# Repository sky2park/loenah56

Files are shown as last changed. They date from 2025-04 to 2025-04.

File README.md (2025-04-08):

# loenah56
Loenah56, A split-keyboard with 56 keys.

# How to flash firmware
Use qmk toolbox. Copy loenah folder to qmk toolbox keyboard folder.

Connect one side with bootloader mode. Execute qmk toolbox and execute below line.

qmk flash -kb loenah -km default -bl uf2-split-left (for left)

qmk flash -kb loenah -km default -bl uf2-split-right (for right)

Connect other side and do as same.

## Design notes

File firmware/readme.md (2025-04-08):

# loenah

loenah

*A short description of the keyboard/project*

* Keyboard Maintainer: [Park](https://github.com/sky2park)
* Hardware Supported: *The PCBs, controllers supported*
* Hardware Availability: *Links to where you can find this hardware*

Make example for this keyboard (after setting up your build environment):

    make loenah:default

Flashing example for this keyboard:

    make loenah:default:flash

See the [build environment setup](https://docs.qmk.fm/#/getting_started_build_tools) and the [make instructions](https://docs.qmk.fm/#/getting_started_make_guide) for more information. Brand new to QMK? Start with our [Complete Newbs Guide](https://docs.qmk.fm/#/newbs).

## Bootloader

Enter the bootloader in 3 ways:

* **Bootmagic reset**: Hold down the key at (0,0) in the matrix (usually the top left key or Escape) and plug in the keyboard
* **Physical reset button**: Briefly press the button on the back of the PCB - some may have pads you must short instead
* **Keycode in layout**: Press the key mapped to `QK_BOOT` if it is available

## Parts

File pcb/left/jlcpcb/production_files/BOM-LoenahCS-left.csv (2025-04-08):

Comment | Designator | Footprint | LCSC | Quantity
Resistor | R1,R2 | Resistor_0402 | C25905 | 2
MX_SW_HS | MX1,MX10,MX11,MX12,MX13,MX14,MX15,MX16,MX17,MX18,MX19,MX2,MX20,MX21,MX22,MX23,MX24,MX25,MX26,MX27,MX28,MX3,MX4,MX5,MX6,MX7,MX8,MX9 | SW_MX_HS_CPG151101S11_1u | C41430893 | 28
D_Small | D1,D10,D11,D12,D13,D14,D15,D16,D17,D18,D19,D2,D20,D21,D22,D23,D24,D25,D26,D27,D28,D3,D4,D5,D6,D7,D8,D9 | D_SOD-123 | C83528 | 28

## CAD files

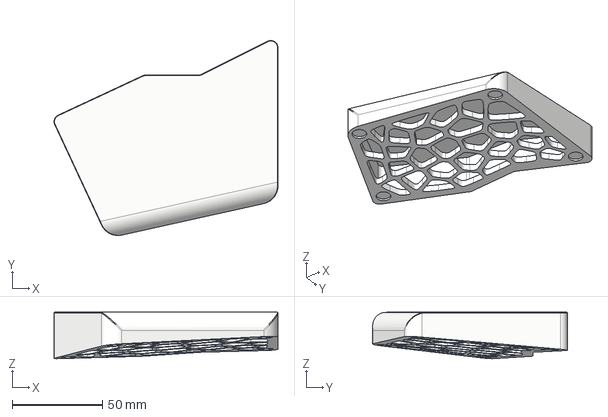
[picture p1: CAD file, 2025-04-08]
case/palmrest_right.step
124.4 x 108.3 x 25.8 mm

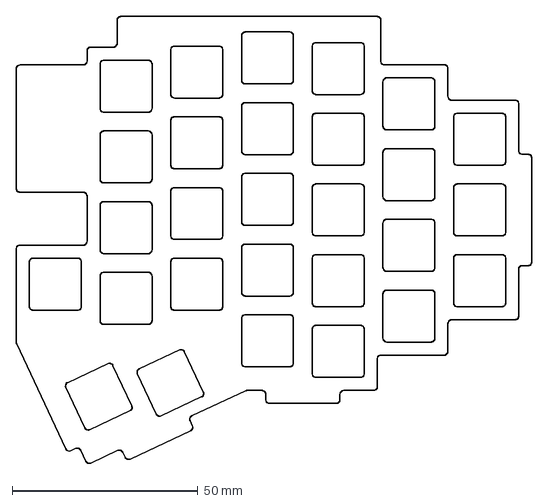
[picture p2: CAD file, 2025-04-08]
plate/plate_right.dxf
138.9 x 120.4 mm

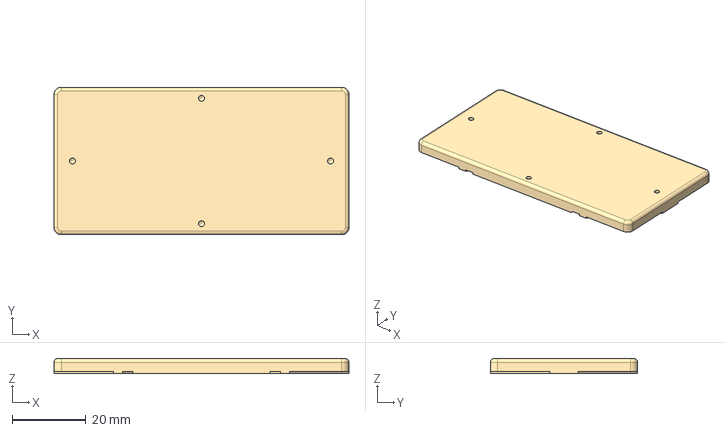
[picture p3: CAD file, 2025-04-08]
case/counterweight.step
80.0 x 40.0 x 4.00 mm

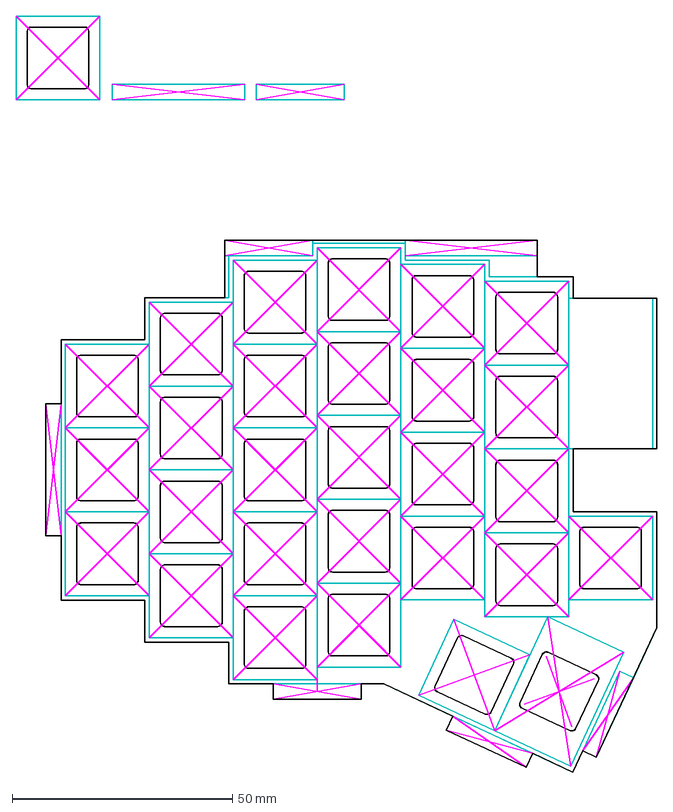
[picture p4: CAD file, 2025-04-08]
plate/design_criteria.dxf
145.6 x 171.7 mm

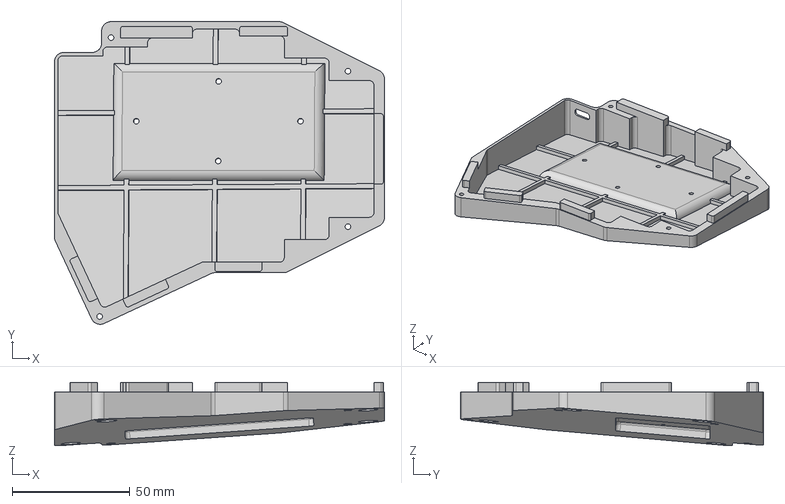
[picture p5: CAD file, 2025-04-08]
case/bottom_right.step
140.4 x 128.7 x 26.9 mm

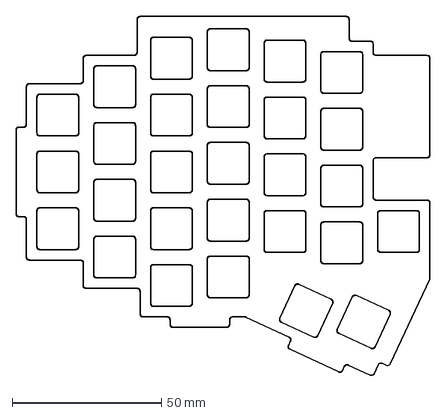
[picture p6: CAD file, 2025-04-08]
plate/plate_left.dxf
138.9 x 120.4 mm

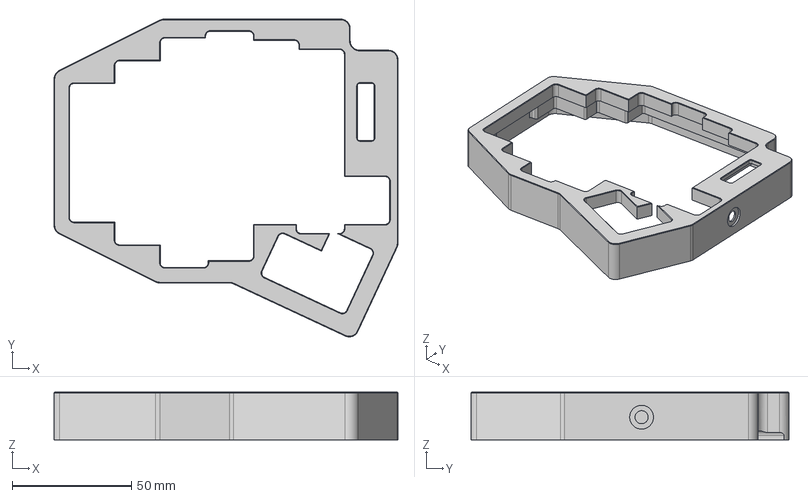
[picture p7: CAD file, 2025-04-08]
case/top_left.step
144.3 x 133.4 x 20.0 mm

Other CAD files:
case/palmrest_left.step
case/bottom_left.step
case/top_right.step

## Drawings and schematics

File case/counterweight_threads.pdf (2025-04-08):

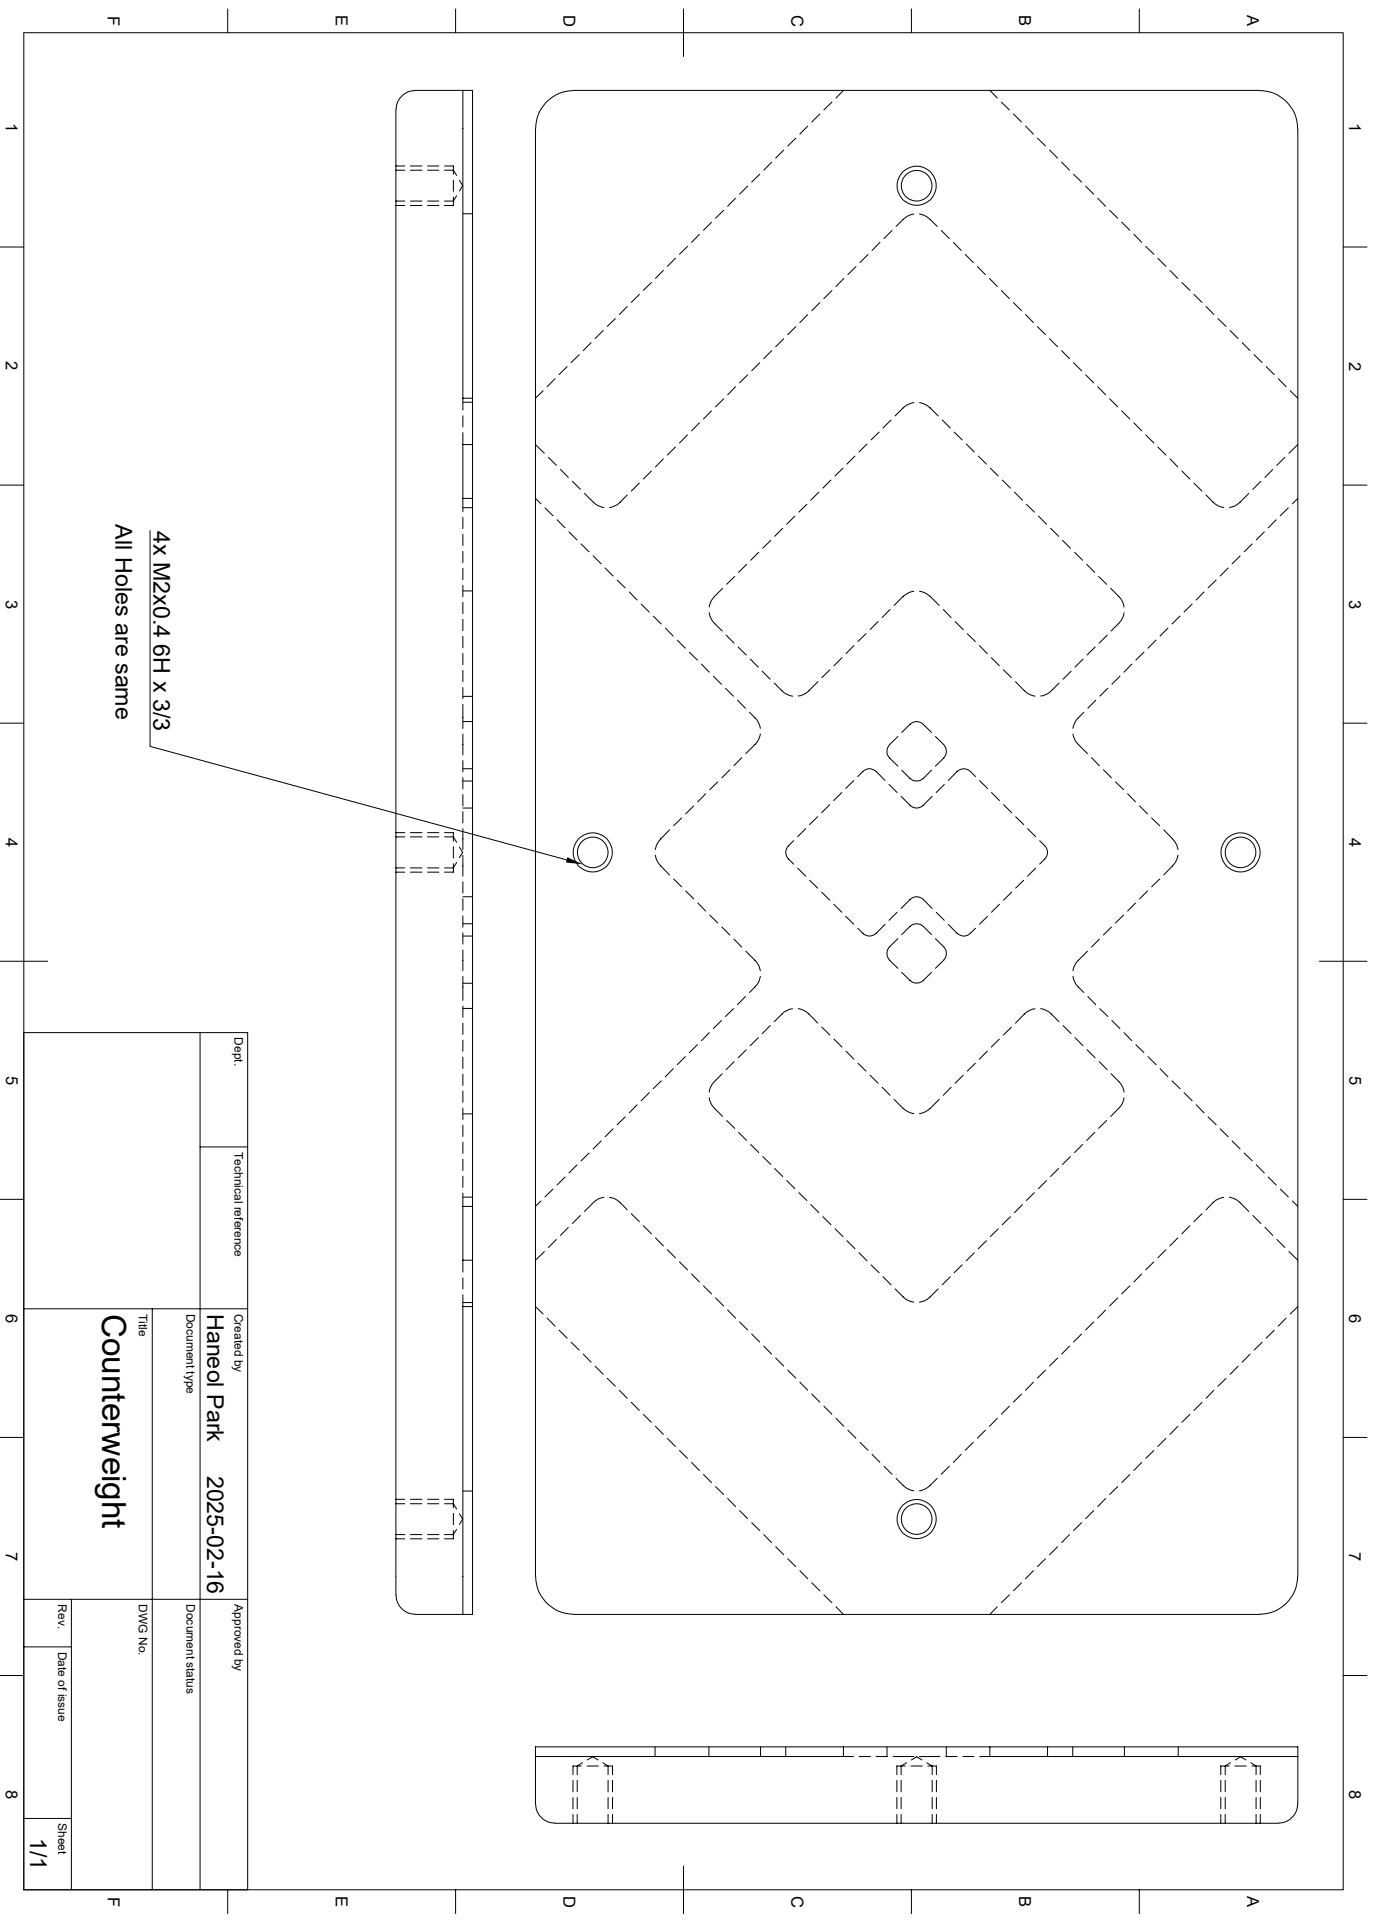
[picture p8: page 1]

1 A 2 3 4 5 6 7 8 1 2 3 4 5 6 7 8 FEDCB FEDCBA Dept. Technical reference Created by Approved by Title DWG No. Document type Document status Rev. Date of issue Sheet 2025-02-16 1/1 Counterweight Haneol Park All Holes are same 4x M2x0.4 6H x 3/3

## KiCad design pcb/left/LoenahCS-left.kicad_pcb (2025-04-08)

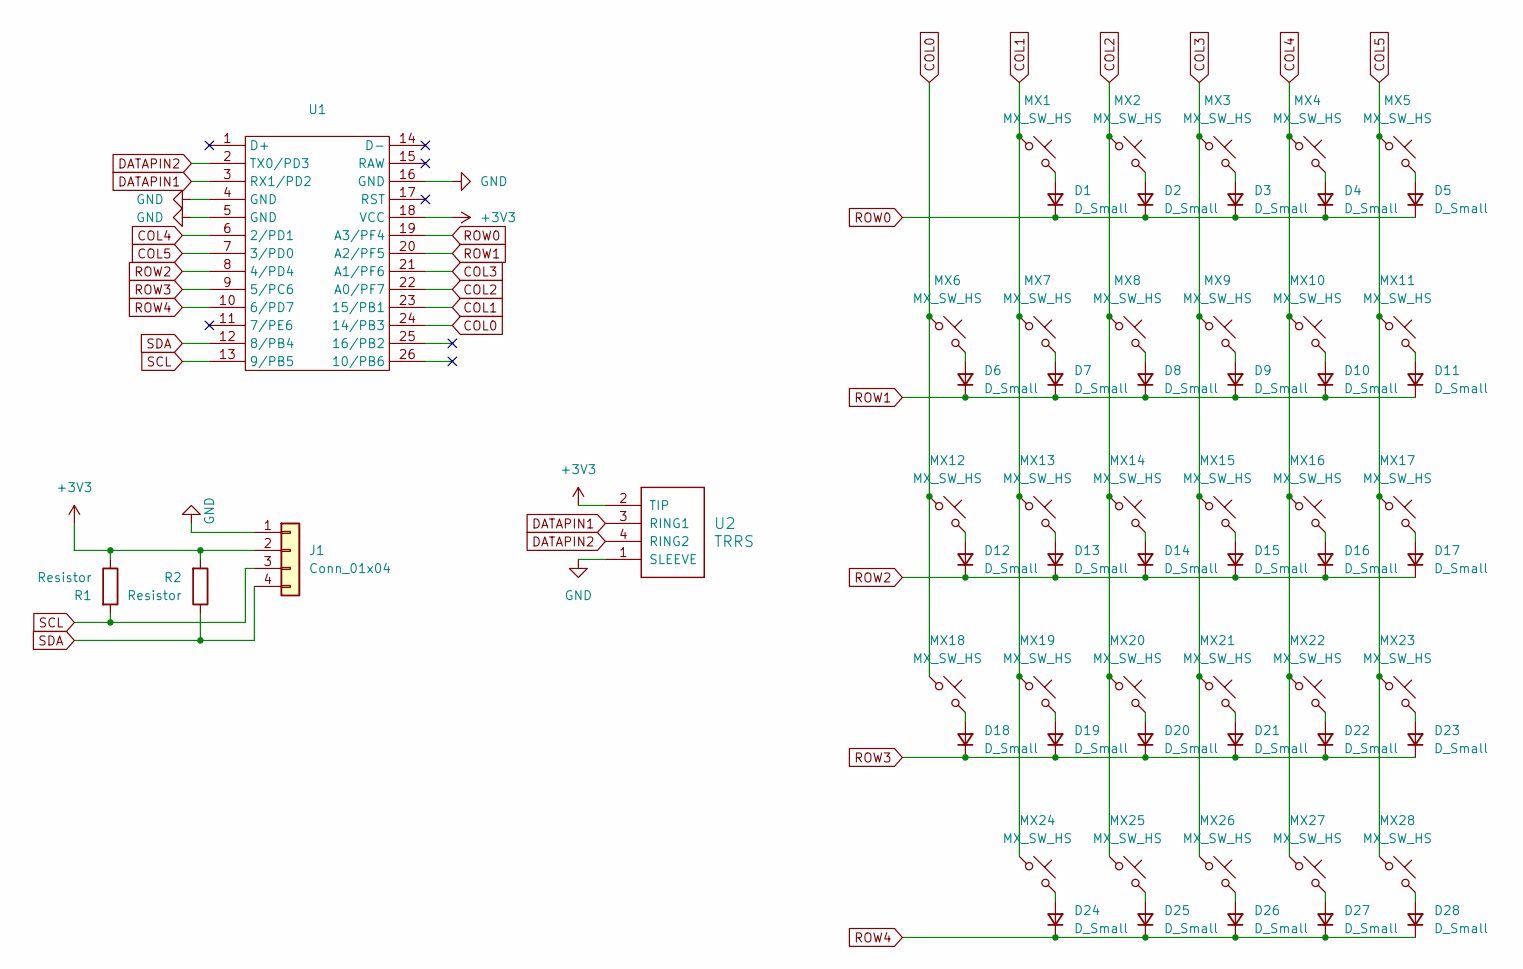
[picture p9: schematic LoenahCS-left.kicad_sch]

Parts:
D1, D2, D3, D4, D5, D6, D7, D8, D9, D10, D11, D12, D13, D14, D15, D16, D17, D18, D19, D20, D21, D22, D23, D24, D25, D26, D27, D28: D_Small; D_SOD-123
J1: Conn_01x04; PinHeader_1x04_P2.54mm_Vertical
MX1, MX2, MX3, MX4, MX5, MX6, MX7, MX8, MX9, MX10, MX11, MX12, MX13, MX14, MX15, MX16, MX17, MX18, MX19, MX20, MX21, MX22, MX23, MX24, MX25, MX26, MX28: MX_SW_HS; SW_MX_HS_CPG151101S11_1u
MX27: MX_SW_HS; SW_MX_HS_CPG151101S11_1.5u
R1, R2: Resistor; Resistor_0402
U1: Adafruit_KB2040
U2: TRRS; TRRS_PJ-320A

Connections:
+3V3: J1.2, R1.1, R2.2, U1.18 (VCC), U2.2 (TIP)
COL0: MX6.1, MX12.1, MX18.1, U1.24 (14/PB3)
COL1: MX1.1, MX7.1, MX13.1, MX19.1, MX24.1, U1.23 (15/PB1)
COL2: MX2.1, MX8.1, MX14.1, MX20.1, MX25.1, U1.22 (A0/PF7)
COL3: MX3.1, MX9.1, MX15.1, MX21.1, MX26.1, U1.21 (A1/PF6)
COL4: MX4.1, MX10.1, MX16.1, MX22.1, MX27.1, U1.6 (2/PD1)
COL5: MX5.1, MX11.1, MX17.1, MX23.1, MX28.1, U1.7 (3/PD0)
DATAPIN1: U1.3 (RX1/PD2), U2.3 (RING1)
DATAPIN2: U1.2 (TX0/PD3), U2.4 (RING2)
GND: J1.1, U1.4 (GND), U1.5 (GND), U1.16 (GND), U2.1 (SLEEVE)
unnamed: D1.2 (A), MX1.2
unnamed: D2.2 (A), MX2.2
unnamed: D3.2 (A), MX3.2
unnamed: D4.2 (A), MX4.2
unnamed: D5.2 (A), MX5.2
unnamed: D6.2 (A), MX6.2
unnamed: D7.2 (A), MX7.2
unnamed: D8.2 (A), MX8.2
unnamed: D9.2 (A), MX9.2
unnamed: D10.2 (A), MX10.2
unnamed: D11.2 (A), MX11.2
unnamed: D12.2 (A), MX12.2
unnamed: D13.2 (A), MX13.2
unnamed: D14.2 (A), MX14.2
unnamed: D15.2 (A), MX15.2
unnamed: D16.2 (A), MX16.2
unnamed: D17.2 (A), MX17.2
unnamed: D18.2 (A), MX18.2
unnamed: D19.2 (A), MX19.2
unnamed: D20.2 (A), MX20.2
unnamed: D21.2 (A), MX21.2
unnamed: D22.2 (A), MX22.2
unnamed: D23.2 (A), MX23.2
unnamed: D24.2 (A), MX24.2
unnamed: D25.2 (A), MX25.2
unnamed: D26.2 (A), MX26.2
unnamed: D27.2 (A), MX27.2
unnamed: D28.2 (A), MX28.2
ROW0: D1.1 (K), D2.1 (K), D3.1 (K), D4.1 (K), D5.1 (K), U1.19 (A3/PF4)
ROW1: D6.1 (K), D7.1 (K), D8.1 (K), D9.1 (K), D10.1 (K), D11.1 (K), U1.20 (A2/PF5)
ROW2: D12.1 (K), D13.1 (K), D14.1 (K), D15.1 (K), D16.1 (K), D17.1 (K), U1.8 (4/PD4)
ROW3: D18.1 (K), D19.1 (K), D20.1 (K), D21.1 (K), D22.1 (K), D23.1 (K), U1.9 (5/PC6)
ROW4: D24.1 (K), D25.1 (K), D26.1 (K), D27.1 (K), D28.1 (K), U1.10 (6/PD7)
SCL: J1.3, R1.2, U1.13 (9/PB5)
SDA: J1.4, R2.1, U1.12 (8/PB4)

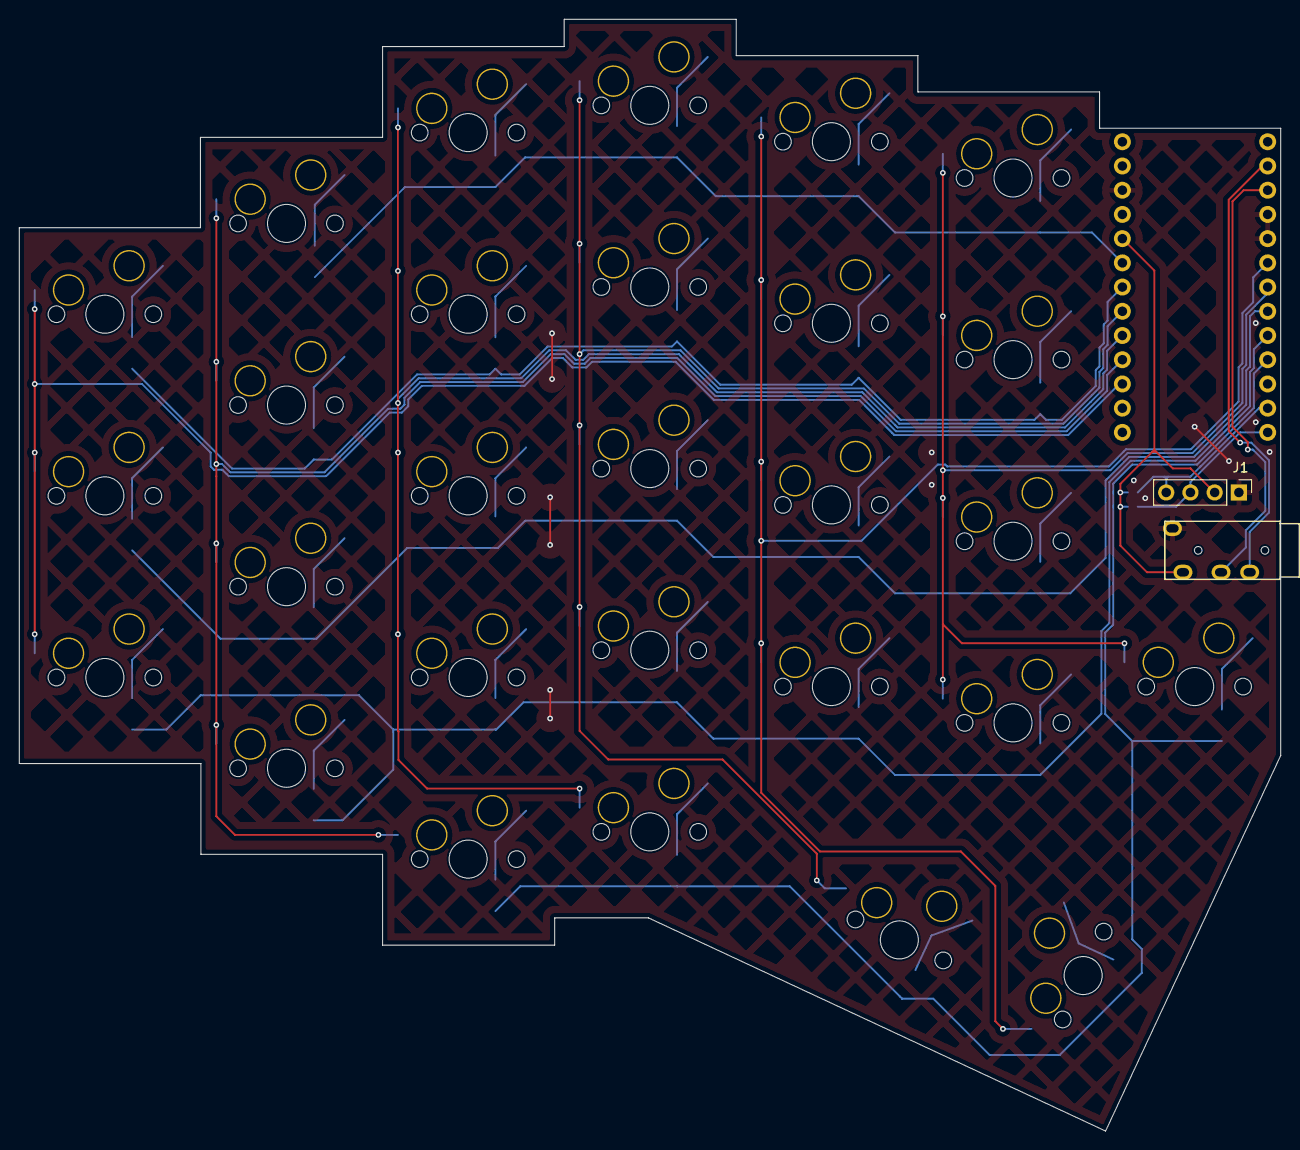
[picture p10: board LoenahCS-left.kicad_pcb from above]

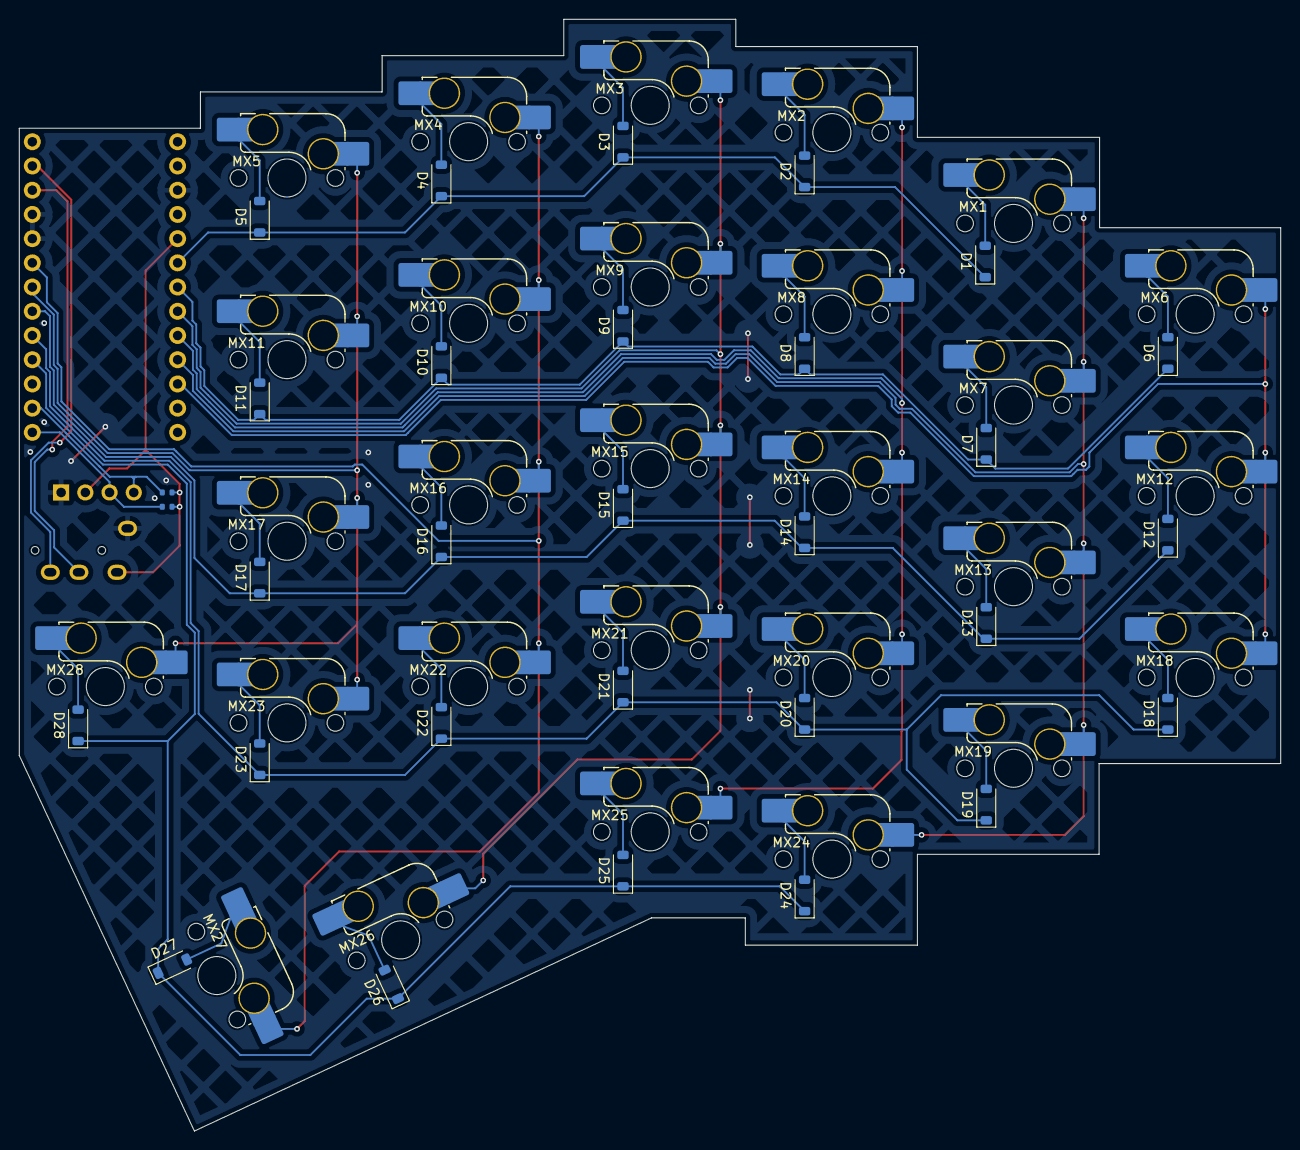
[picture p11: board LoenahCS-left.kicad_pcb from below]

Board: 2 copper layers, 132.3 x 116.6 mm, 61 parts (59 on the bottom side), 45 nets.

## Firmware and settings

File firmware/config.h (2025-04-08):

#pragma once

#define OLED_FONT_H "keyboards/loenah/lib/glcdfont.c"

#define EE_HANDS											// Flash handedness to each side (-bl uf2-split-left/right)
#define RP2040_BOOTLOADER_DOUBLE_TAP_RESET 					// Enable double-tapping reset button to enter bootloader mode
#define RP2040_BOOTLOADER_DOUBLE_TAP_RESET_TIMEOUT 500U		// How quickly reset button must be tapped to enter bootloader mode

#define BOOTMAGIC_ROW 0
#define BOOTMAGIC_COLUMN 1
#define BOOTMAGIC_ROW_RIGHT 5
#define BOOTMAGIC_COLUMN_RIGHT 4

#define SERIAL_USART_FULL_DUPLEX    						// USART full duplex
#define SERIAL_USART_TX_PIN GP0     						// USART TX pin
#define SERIAL_USART_RX_PIN GP1     						// USART RX pin

#define I2C_DRIVER I2CD0									// I2C driver for oled display
#define I2C1_SDA_PIN GP8									// Oled display SDA pin
#define I2C1_SCL_PIN GP9									// Oled display SCL pin

#define SPLIT_WPM_ENABLE

#define SECOND_TO_MS 1000 // 1 seconds & 1000 milliseconds

#ifdef OLED_ENABLE
	#define OLED_TIMEOUT 90 * SECOND_TO_MS  // 1.5 minutes of no activity to turn OLED off
#endif
